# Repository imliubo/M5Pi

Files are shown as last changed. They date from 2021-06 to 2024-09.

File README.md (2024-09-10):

# M5Pi
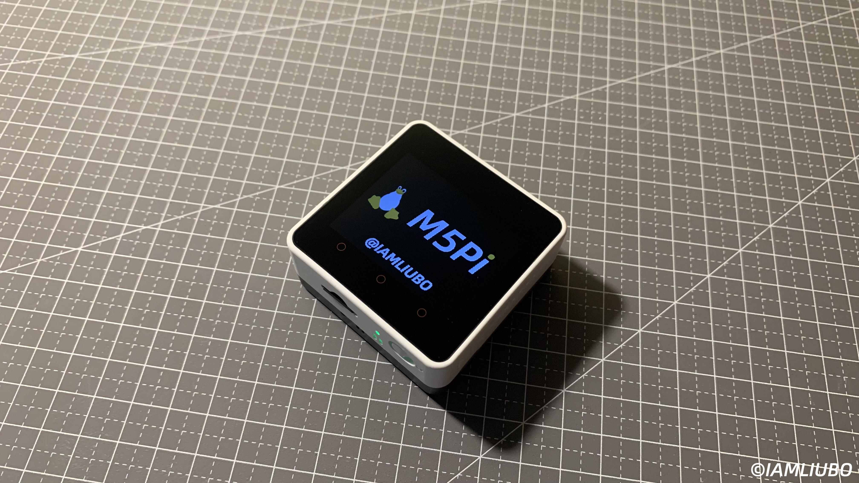
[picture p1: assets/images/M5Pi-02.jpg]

M5Pi is an open source Linux embedded development board, using Allwinner F1C200s CPU, and has a beautiful shell.

## Try to use a pre-compiled system image
```shell
wget https://github.com/imliubo/M5Pi/releases/download/v0.1-alpha/M5Pi-sysimage-sdcard-v0.1-alpha.tar.gz
tar -zxvf M5Pi-sysimage-sdcard-v0.1-alpha.tar.gz
dd if=sysimage-sdcard.img of=/dev/sdX  # Please make sure "X" is your TF card mount point.
```

## Try to compile your custom system image

### Install
```shell
sudo apt install wget unzip build-essential git bc swig libncurses-dev libpython3-dev libssl-dev
sudo apt install python3-distutils
```

### Build
```shell
git clone --recursive https://github.com/imliubo/M5Pi
cd M5Pi/buildroot-M5Pi
make IAMLIUBO_m5pi_defconfig  # Use the default config.
make -j ${YOUR_CPU_COUNT}
```

### Build with custom config
```shell
make menuconfig
make uboot-menuconfig
make linux-menuconfig
```

### Flash
```shell
dd if=buildroot-M5Pi/output/images/sysimage-sdcard.img of=/dev/sdX  # Please make sure "X" is your TF card mount point.
```

## License
1. Hardware: CC BY-NC-SA 4.0
2. buildroot-M5Pi: follow the upstream

## Links
[【自 制】这 可 能 是 最 精 致 的 Pi 了【Linux 小主机 | 开 源 | 硬 核】](https://www.bilibili.com/video/BV1RV411W7eH/)

[[开源项目-记录贴]扔掉你手中的开发板，跟我来自制基于F1C100s/F1C200s的M5Pi吧!](https://whycan.com/t_6402.html)

[How-to-make-a-M5Pi](./Tutorials/How-to-make-a-M5Pi.md)

## Thanks to the sponsor Seeed!
Seeed Fusion PCB Assembly Service offers one-stop prototyping for PCB manufacture, PCB assembly and as a result they produce superior quality PCBs and Fast Turnkey PCBA from 7 working days. When you prototype with Seeed Fusion, they can definitely provide Free DFA and Free functional tests for you! Check out their website to know more: https://www.seeedstudio.com/prototype-pcb-assembly.html

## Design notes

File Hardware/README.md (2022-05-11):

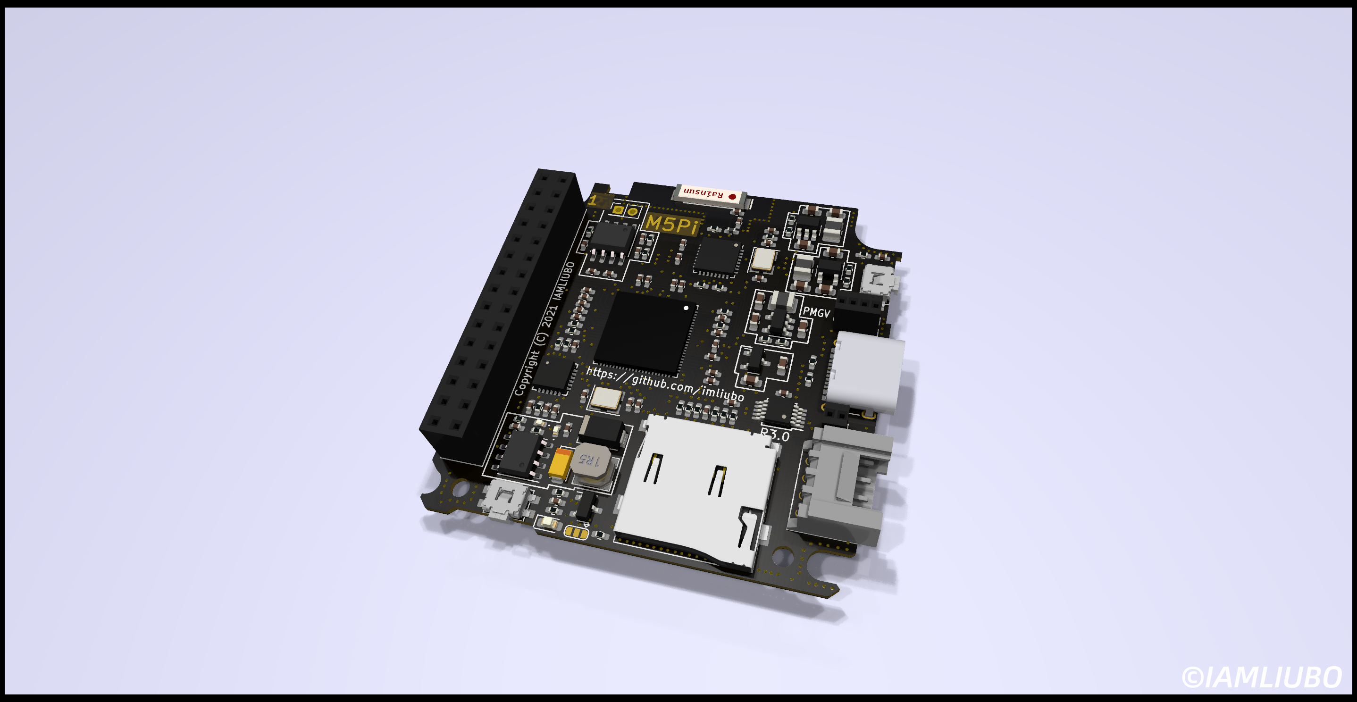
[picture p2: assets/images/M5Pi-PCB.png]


### CAUTION 

Please use the kicad-nightly version to open the projects.

etc. 
```bash
Version: 6.99.0-unknown-c34fb494b1~148~ubuntu20.04.1, release build
```

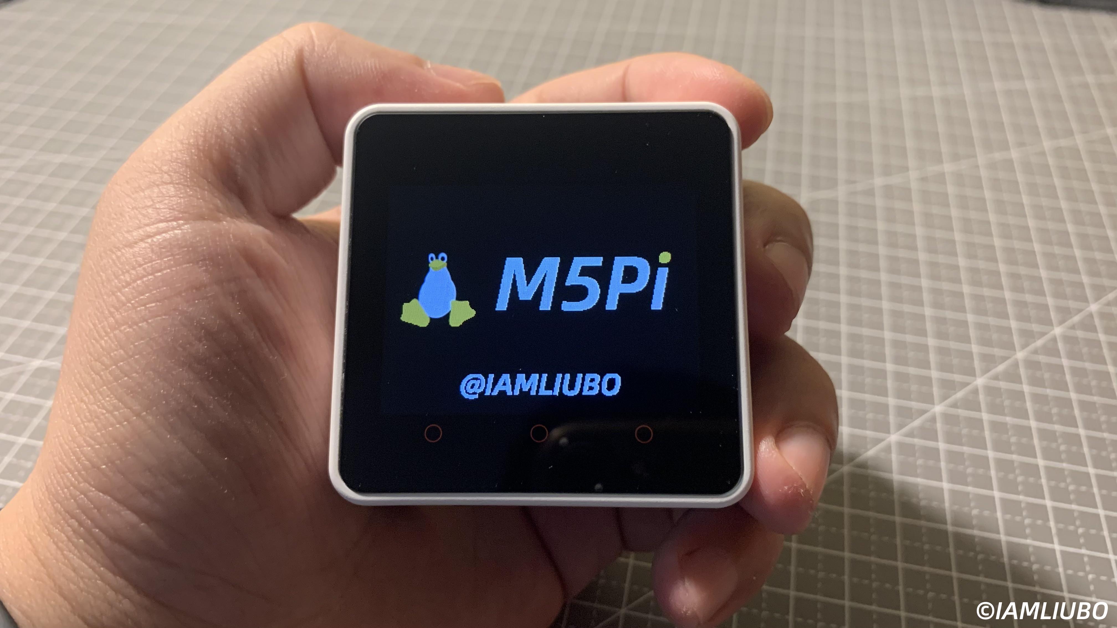
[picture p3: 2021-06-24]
assets/images/M5Pi-01.jpg

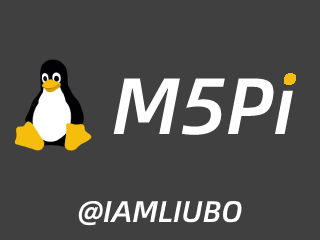
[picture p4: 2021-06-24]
assets/images/M5Pi.png

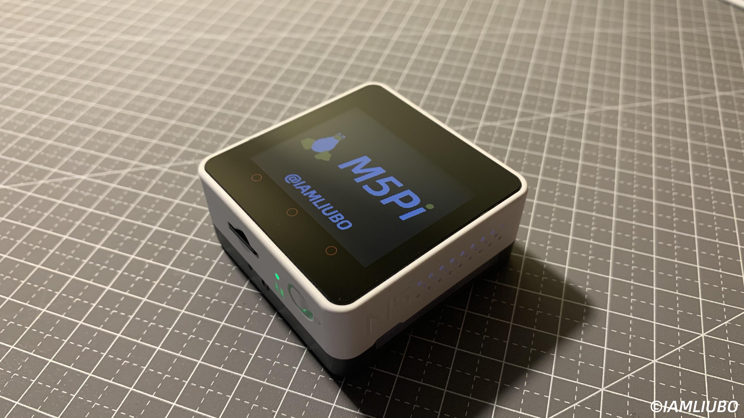
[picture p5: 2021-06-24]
assets/images/M5Pi-03.jpg

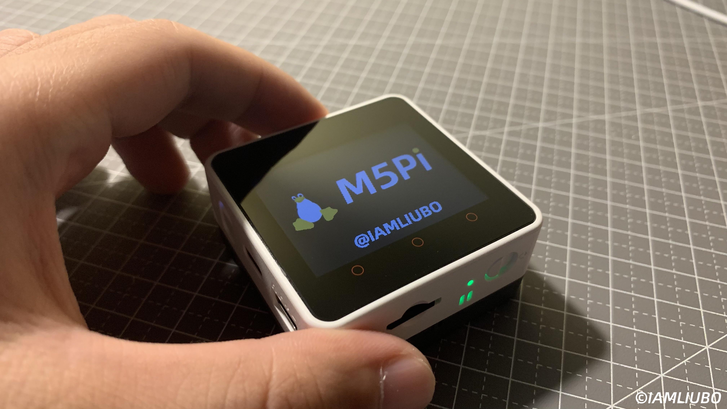
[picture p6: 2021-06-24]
assets/images/M5Pi-04.jpg

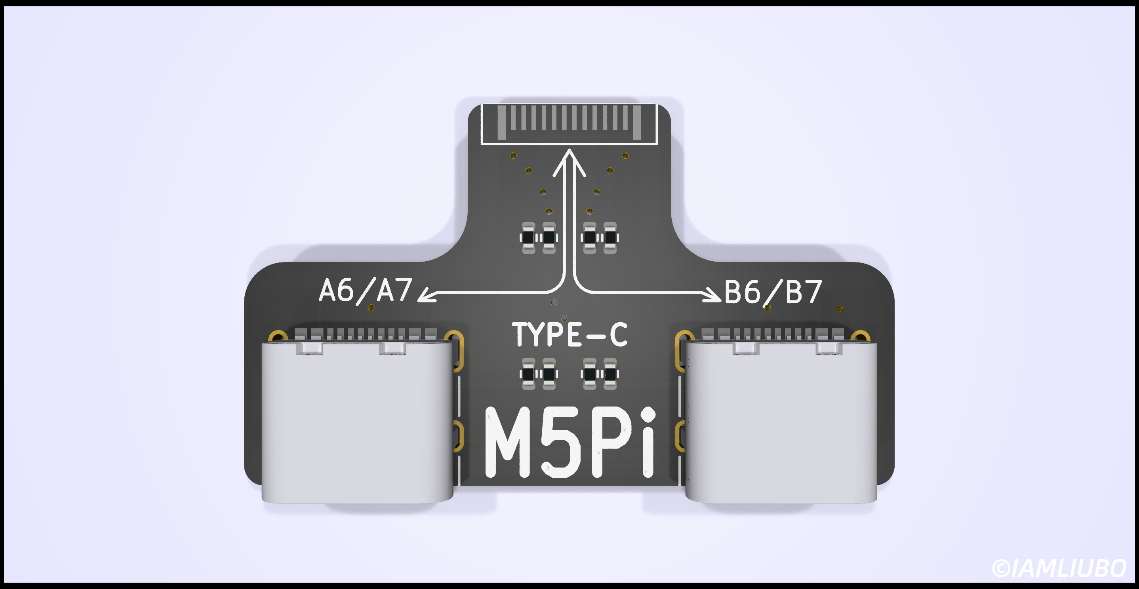
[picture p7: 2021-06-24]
assets/images/M5Pi-TYPE-C.png

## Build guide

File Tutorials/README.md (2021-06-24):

# Tutorials
The tutorial is not ready yet.

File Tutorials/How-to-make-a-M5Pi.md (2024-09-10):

# How to make a M5Pi :)

## 是什么

M5Pi是我最近自制并开源的嵌入式Linux开发板，基于全志科技的F1C200s芯片，板载MPU6050姿态传感器，拥有一个320x240分辨率，2寸大小的全贴合电容触摸显示屏，一个1W的小喇叭可以用来播放声音，Wi-Fi用的是ESP8089，最重要的是有一个精美的外壳，这也是为什么我称它为最精致的“Pi”的原因，项目完全开源，PCB使用的开源软件KiCAD绘制，部分3D模型使用的开源软件FreeCAD绘制，系统使用的比较流行的buildroot制作，还用LVGL写了个简单的Launcher(还没完全写完)。



## 为什么做

其实接触嵌入式Linux已经蛮久了，从最开始的树莓派，到后来NanoPi、香橙派、荔枝派等等，基本上也是都有玩过，还在B站录制过几集纯萌新入门视频，不过平常工作也不是主要做Linux相关的，所以理解的和讲的都很浅薄，真正让自己想要从零开始做一个属于自己的“Pi”，还是去年看到稚晖做的小电脑，当时觉得非常不错，自己也想去做一个，不过后面实际尝试了下，难度系数还是颇高的，所以当时用ESP32-S2做了个单片机版的小电视玩了玩，不过这个想法从未消失。


[](https://www.bilibili.com/video/BV19p4y1Q7yP)

## 做了哪些尝试

第二次想做，应该是在去年的十一月份左右，因为当时M5Core2玩了蛮久了，觉得这个尺寸，这个外壳，还有触摸的屏幕简直是太棒了，刚好我近水楼台先得月，手头也有外壳也有显示屏，所以当时又想去尝试一下，还特地选择了全志的H5，然后各种逛论坛，找资料，下载资料，真正开始要画PCB的时候，就觉得还是差点儿事了，因为H5没有内置DDR，我还想加一个eMMC，这部分属于高速PCB范畴了，挺难整的，只是简单打了一版布局的PCB，看了看主要元器件就放弃了，因为受制于外壳的尺寸，正面空间还是蛮小的，放背面我还不确定跟屏幕会不会有干涉，以及发热会不会影响屏幕等，就又咕掉了。

背面还有两颗DDR，还没layout就觉得难整了


不过也没有完全咕掉，我还是成功曲线救国，做了一版试了试，不过是用的友善之臂的NanoPi NEO Air核心板，然后画了个扩展版，成功试制了一版，虽然曲线救国，尺寸也不太合适等等众多小问题，但是效果还是非常棒的!跑的是Armbian，驱动屏幕的时候也是翻车了很久，怎么搞都没法点亮，最后发现问题是FPC座子虚焊了... 当时差点儿想拍死自己。



正面看还是蛮不错的，但是看看背面就有点惨不忍睹了...


## 怎么做的

用NanoPi搞完后，就懒惰了(其实是菜)，想用性能高点的CPU，PCB搞不定，PCB能搞定的，性能又不高，陷入了很长时间的CPU选型阶段，总体思想就是选内置DDR的，性能还要高点的，其实刚开始M5Pi没有准备用F1C200s，当时是看上了SSD202，因为刚好我司在做一个项目(Unit V2)，刚好也了解一点，但是这个片子的资料需要签NDA，那我后期开源肯定会受到影响，所以还不如选择一款大家用的多，虽然官方也没公开release过任何资料的片子，最后的焦点就放在了F1C和V3s上，虽然V3s性能要比F1C高，但是价格还是要贵一丢丢，而且第一次做，还是找个便宜点的吧，于是就这样定了下来，四月底就正式开始搞了，内置DDR的片子画起来，要简单很多，基本上只要电源没问题，晶振没问题，就可以正常跑起来了...(省略几千字，开发记录可以在坑网看到，链接在文章最后)




PCB第一版就可以正常运行，只不过触摸跟LED都画反了，别的没什么大碍，然后软件开发也就挺顺利的，因为aodzip大佬已经做了很多适配了，所以就简单改改设备树之类的，就平平无奇的运行起来了，不如上一次因为焊接问题，结果搞了好几天软件有意思(ahhhh)，有点凡尔赛了，其实从开始做，到正常运行还是花了蛮久的时间的，基本都是周末搞，PCB其实也打了好几版，主要是布局好，为了看结构需要打板测试。开发过程中最崩溃的莫过于焊接了，说多了都是泪，焊接太费事了...



## 收获了什么

M5Pi做了很久，做的还是非常开心的，这种感觉只有自己亲自去做，然后一点点调试，调试一个功能就行一个功能的感觉妙不可言~ 完整的做一个小项目还是比较爽的，建议大家也可以去尝试下，B站很多同学私信我是怎么学习，怎么开发的，我觉得还是多动手，多实践是最好的方法。M5Pi还没有完全开发完成，不过我已经开始着手准备下一个版本了！



## 大感谢

做M5Pi的过程中也收到了很多人的帮助，首先感谢哇酷网(原坑网)的各位坛友，然后是我的BOSS，哈哈，免费提供了我几套外壳(遗憾的是显示屏仓库缺货)，还有实验室可以让我在周末瞎搞，再然后是全志的Kirin，还送了我一个哪吒D1开发板，最后就是将各种问题记录并分享出来的网友们!

最后，项目是开源的，可以在我的Github仓库找到。

## 相关链接

1. https://github.com/imliubo/M5Pi
2. https://www.bilibili.com/video/BV1RV411W7eH
3. https://whycan.com/viewtopic.php?id=6402&action=onlyshowauthor

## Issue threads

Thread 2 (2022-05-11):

error when open kicad file in R4 folder

kawashimaken, 2022-05-11:
Thank you for sharing this great project!

An error occurred when opening the KiCad file in the R4 folder.
The KiCad file in R3 folder had no problem.
I am using KiCad 6.01 (6.05 shows the same error), should I switch to KiCad 5? or Do I have to use a specific version of KiCad?
Thank you!

imliubo, 2022-05-11:
Sorry,I must not have mentioned, I am using kicad-nightly, please try again with the kicad-nighly version.

kawashimaken, 2022-05-11:
Thank you!
I will try kicad-nighly next!

Closed 2022-05-17.

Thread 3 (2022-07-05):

kicad封装问题

apple596, 2022-07-05:
请问kicad的F1C200S的封装和原理图是在哪里找的，非常感谢。

imliubo, 2022-07-27:
好像是[这里](https://www.thirtythreeforty.net/)

Closed 2022-08-23.

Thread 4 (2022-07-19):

M5Pi-Launcher中的库缺少CMakeList.txt，编译失败

xxzling, 2022-07-19:
您好，M5Pi-Launcher中的库缺少CMakeList.txt，例如lv_fs_if、nes等，导致编译失败，手动添加内容为file(GLOB SOURCES *.c)后又不能生成*.a文件，请问有什么解决方法吗？

imliubo, 2022-08-23:
看一下 [M5Pi-Launcher](https://github.com/imliubo/M5Pi-Launcher/tree/870a251a8f5348b5696e45d8034bc286631881a7)中的 patch 文件夹和 顶层 CMakeList.tx

Closed 2022-10-10.

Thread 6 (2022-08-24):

power and buttons and network

sp00ck, 2022-08-24:
Is possible add knob/rotor for setup, change volume etc.
and outside (on edges) 2-3 buttons

I think the 18650 power will be great but not one but 2 independent. 2 different size (capacity) or old and new
charging separately and use separately. For example when device work i can get battery and put it to flashlight and device still work or... this same. When my computer have less power i can replace one cell from my mp3 player.

I hate sd card, why not using normal usb host A ? normal flash disk for system. cheap and usefull.
And please add irda (infrared)

for increase working time meybe put phisical switch for every system, turn off screen, sound, irda, meybe decrease speed of memory or cpu.

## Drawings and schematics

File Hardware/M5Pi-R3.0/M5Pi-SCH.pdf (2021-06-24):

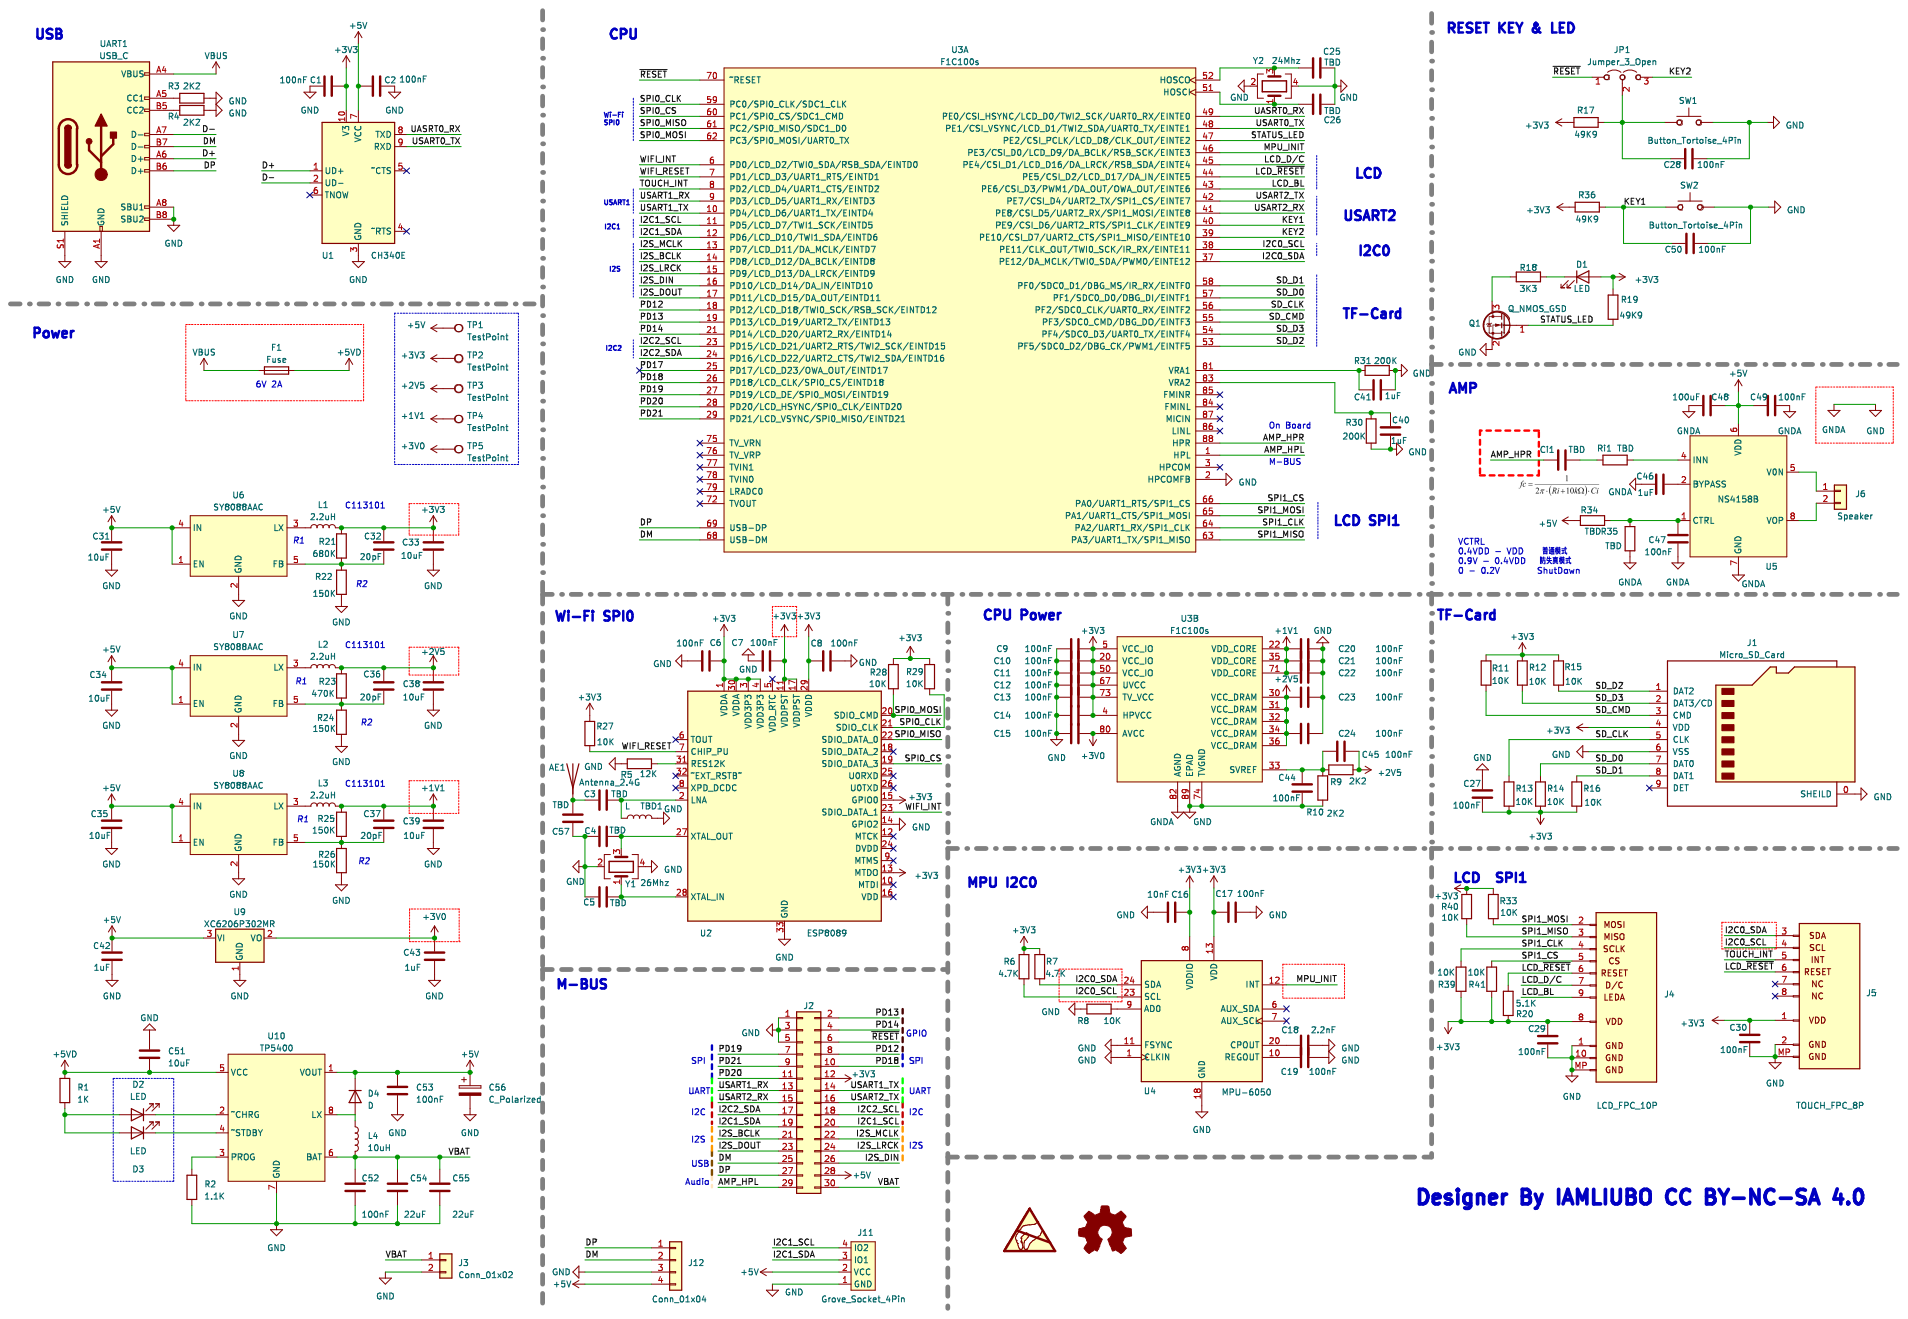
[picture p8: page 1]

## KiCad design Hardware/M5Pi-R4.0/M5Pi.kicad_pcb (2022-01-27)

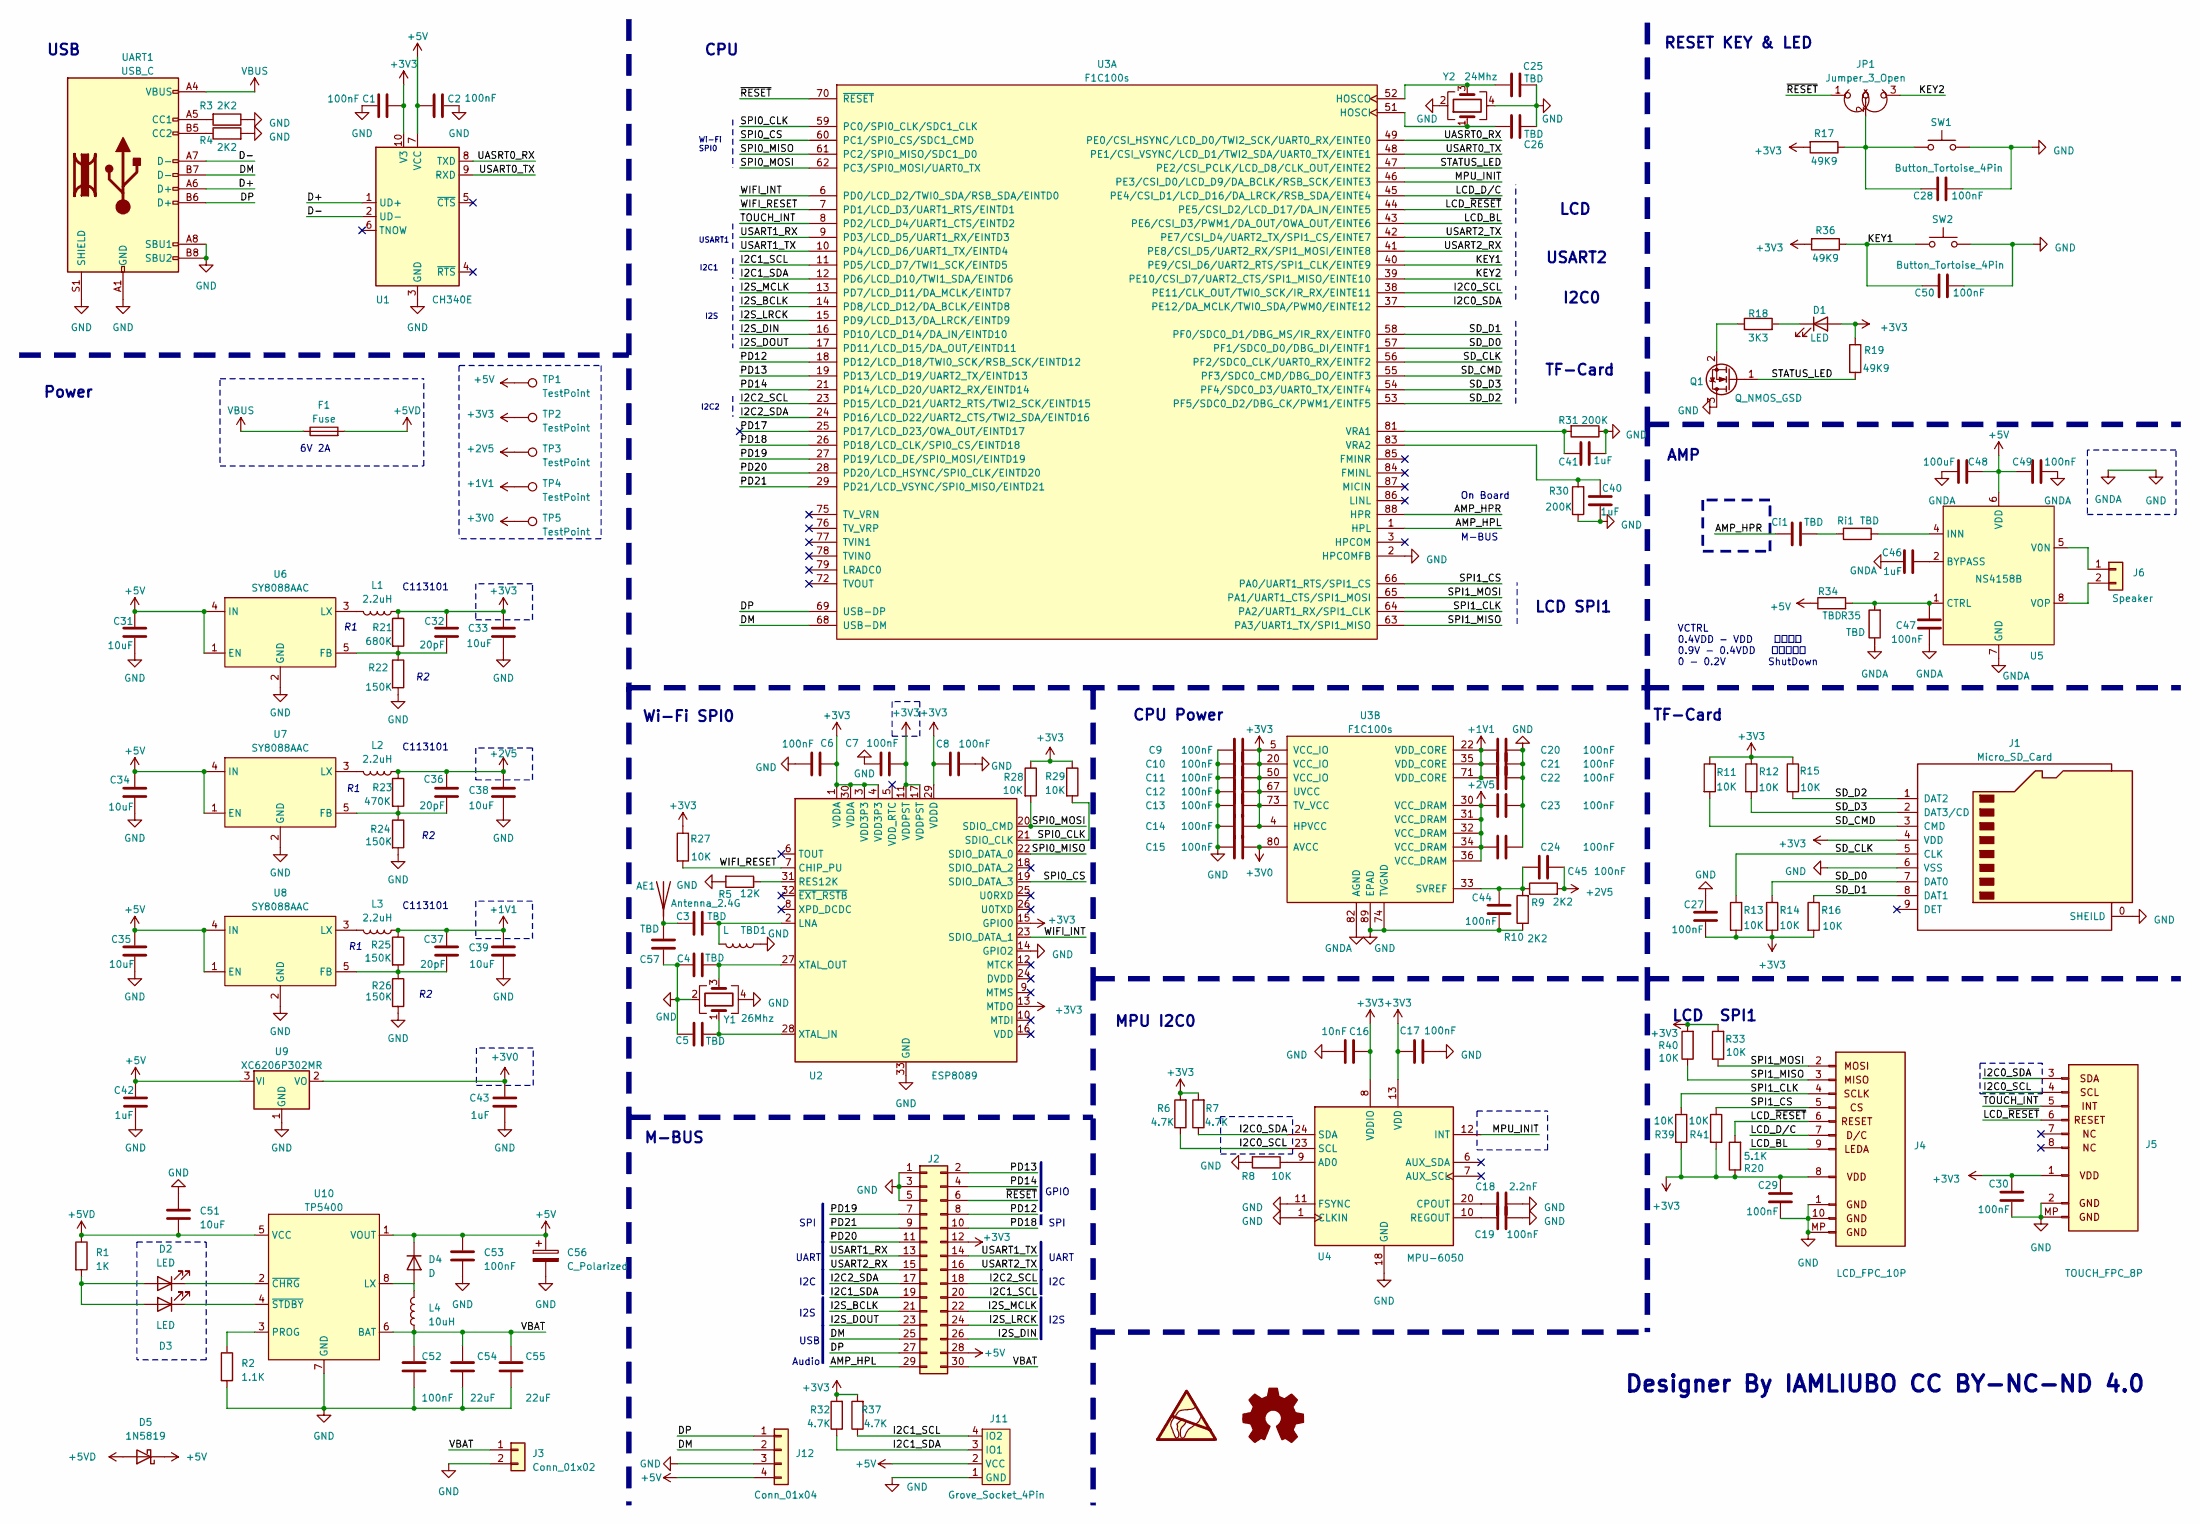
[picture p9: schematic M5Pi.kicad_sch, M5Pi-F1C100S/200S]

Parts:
AE1: Antenna_2.4G; ANT-2.4GHZ-9.5X2.0MM
C1, C2, C6, C7, C8, C9, C10, C11, C12, C13, C14, C15, C17, C19, C20, C21, C22, C23, C24, C27, C28, C29, C30, C44, C45, C47, C49, C50, C52, C53: 100nF; C_0402_1005Metric_Pad0.74x0.62mm_HandSolder
C3, C4, C5, C25, C26, C57: TBD; C_0402_1005Metric_Pad0.74x0.62mm_HandSolder
C16: 10nF; C_0402_1005Metric_Pad0.74x0.62mm_HandSolder
C18: 2.2nF; C_0402_1005Metric_Pad0.74x0.62mm_HandSolder
C31, C33, C34, C35, C38, C39: 10uF; C_0603_1608Metric
C32, C36, C37: 20pF; C_0603_1608Metric
C40, C41, C46: 1uF; C_0402_1005Metric_Pad0.74x0.62mm_HandSolder
C42, C43: 1uF; C_0603_1608Metric
C48: 100uF; C_0402_1005Metric_Pad0.74x0.62mm_HandSolder
C51: 10uF; C_0402_1005Metric_Pad0.74x0.62mm_HandSolder
C54, C55: 22uF; C_0402_1005Metric_Pad0.74x0.62mm_HandSolder
C56: C_Polarized; CP_EIA-3216-10_Kemet-I
Ci1: TBD; C_0402_1005Metric_Pad0.74x0.62mm_HandSolder
D1: LED; LED_0603_1608Metric_Pad1.05x0.95mm_HandSolder
D2, D3: LED; LED_0402_1005Metric
D4: D; D-SMA(DO-214AC)
D5: 1N5819; D_SOD-123
F1: Fuse; Fuse_1206_3216Metric
J1: Micro_SD_Card; MicroSD_Socket_push
J2: Conn_02x15_Odd_Even; PinHeader_2x15_P2.54mm_Vertical
J3: Conn_01x02; PinSocket_1x02_P1.27mm_Vertical
J4: LCD_FPC_10P; TE_1-1734839-0_1x10-1MP_P0.5mm_Horizontal
J5: TOUCH_FPC_8P; TE_0-1734839-8_1x08-1MP_P0.5mm_Horizontal
J6: Speaker; PinHeader_2x01_P2.00mm_Vertical
J11: Grove_Socket_4Pin; Grove_Socket_4Pin_2mm
J12: Conn_01x04; PinSocket_1x04_P1.27mm_Vertical
JP1: Jumper_3_Open; SolderJumper-3_P1.3mm_Open_RoundedPad1.0x1.5mm
L1, L2, L3: 2.2uH; L_1008_2520Metric
L4: 10uH; L_Sunlord_SWPA4030S_4x4x3mm
Q1: Q_NMOS_GSD; SOT-23
R1: 1K; R_0402_1005Metric
R2: 1.1K; R_0402_1005Metric
R3, R4, R9, R10: 2K2; R_0402_1005Metric_Pad0.72x0.64mm_HandSolder
R5: 12K; R_0402_1005Metric_Pad0.72x0.64mm_HandSolder
R6, R7, R32, R37: 4.7K; R_0402_1005Metric_Pad0.72x0.64mm_HandSolder
R8, R11, R12, R13, R14, R15, R16, R27, R28, R29, R33, R39, R40, R41: 10K; R_0402_1005Metric_Pad0.72x0.64mm_HandSolder
R17, R19, R36: 49K9; R_0402_1005Metric_Pad0.72x0.64mm_HandSolder
R18: 3K3; R_0402_1005Metric_Pad0.72x0.64mm_HandSolder
R20: 5.1K; R_0402_1005Metric_Pad0.72x0.64mm_HandSolder
R21: 680K; R_0402_1005Metric
R22, R24, R25, R26: 150K; R_0402_1005Metric
R23: 470K; R_0402_1005Metric
R30, R31: 200K; R_0402_1005Metric_Pad0.72x0.64mm_HandSolder
R34, R35: TBD; R_0402_1005Metric_Pad0.72x0.64mm_HandSolder
Ri1: TBD; R_0402_1005Metric_Pad0.72x0.64mm_HandSolder
SW1, SW2: Button_Tortoise_4Pin; Button_4Pin_Tortoise
TBD1: L; L_0402_1005Metric_Pad0.77x0.64mm_HandSolder
TP1, TP2, TP3, TP4, TP5: TestPoint
U1: CH340E; MSOP-10_3x3mm_P0.5mm
U2: ESP8089; QFN-32-1EP_5x5mm_P0.5mm_EP3.45x3.45mm
U3: F1C100s; QFN-88_EP_10x10_Pitch0.4mm
U4: MPU-6050; InvenSense_QFN-24_4x4mm_P0.5mm
U5: NS4158B; SOP-8_3.9x4.9mm_P1.27mm
U6, U7, U8: SY8088AAC; SOT-23-5
U9: XC6206P302MR; SOT-23
U10: TP5400; SOP-8_4.8x6.0mm_P1.27mm_EP2.3x3.2mm
UART1: USB_C; USB_C_C393939
Y1: 26Mhz; Crystal_SMD_3225-4Pin_3.2x2.5mm
Y2: 24Mhz; Crystal_SMD_3225-4Pin_3.2x2.5mm

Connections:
+1V1: C20.1, C21.1, C22.1, C37.1, C39.1, L3.2, R25.1, TP4.1, U3.22 (VDD_CORE), U3.35 (VDD_CORE), U3.71 (VDD_CORE)
+2V5: C23.1, C24.1, C36.1, C38.1, C45.1, L2.2, R9.2, R23.1, TP3.1, U3.30 (VCC_DRAM), U3.31 (VCC_DRAM), U3.32 (VCC_DRAM), U3.34 (VCC_DRAM), U3.36 (VCC_DRAM)
+3V0: C15.2, C43.1, TP5.1, U3.80 (AVCC), U9.2 (VO)
+3V3: C1.1, C6.1, C7.2, C8.1, C9.2, C10.2, C11.2, C12.2, C13.2, C14.2, C16.1, C17.1, C27.1, C29.2, C30.2, C32.1, C33.1, D1.2 (A), J1.4 (VDD), J2.12, J4.8, J5.1, L1.2, R6.2, R7.2, R11.1, R12.1, R13.2, R14.2, R15.1, R16.2, R17.2, R19.1, R20.1, R21.1, R27.1, R28.1, R29.1, R32.2, R33.2, R36.2, R37.2, R39.2, R40.2, R41.2, TP2.1, U1.10 (V3), U2.1 (VDDA), U2.3 (VDD3P3), U2.4 (VDD3P3), U2.11 (VDDPST), U2.13 (MTDO), U2.15 (GPIO0), U2.17 (VDDPST), U2.29 (VDDD), U2.30 (VDDA), U3.4 (HPVCC), U3.5 (VCC_IO), U3.20 (VCC_IO), U3.50 (VCC_IO), U3.67 (UVCC), U3.73 (TV_VCC), U4.8 (VDDIO), U4.13 (VDD)
+5V: C2.1, C31.1, C34.1, C35.1, C42.1, C48.1, C49.2, C53.1, C56.1, D4.1 (K), D5.1 (K), J2.28, J11.2 (VCC), J12.4, R34.1, TP1.1, U1.7 (VCC), U5.6 (VDD), U6.1 (EN), U6.4 (IN), U7.1 (EN), U7.4 (IN), U8.1 (EN), U8.4 (IN), U9.3 (VI), U10.1 (VOUT)
+5VD: C51.2, D5.2 (A), F1.2, R1.1, U10.5 (VCC)
/AMP_HPL: J2.29, U3.1 (HPL)
/AMP_HPR: Ci1.1, U3.88 (HPR)
/D+: U1.1 (UD+), UART1.A6 (D+)
/D-: U1.2 (UD-), UART1.A7 (D-)
/DM: J2.25, J12.2, U3.68 (USB-DM), UART1.B7 (D-)
/DP: J2.27, J12.1, U3.69 (USB-DP), UART1.B6 (D+)
/I2C0_SCL: J5.4, R6.1, U3.38 (PE11/CLK_OUT/TWI0_SCK/IR_RX/EINTE11), U4.23 (SCL)
/I2C0_SDA: J5.3, R7.1, U3.37 (PE12/DA_MCLK/TWI0_SDA/PWM0/EINTE12), U4.24 (SDA)
/I2C1_SCL: J2.20, J11.4 (IO2), R37.1, U3.11 (PD5/LCD_D7/TWI1_SCK/EINTD5)
/I2C1_SDA: J2.19, J11.3 (IO1), R32.1, U3.12 (PD6/LCD_D10/TWI1_SDA/EINTD6)
/I2C2_SCL: J2.18, U3.23 (PD15/LCD_D21/UART2_RTS/TWI2_SCK/EINTD15)
/I2C2_SDA: J2.17, U3.24 (PD16/LCD_D22/UART2_CTS/TWI2_SDA/EINTD16)
/I2S_BCLK: J2.21, U3.14 (PD8/LCD_D12/DA_BCLK/EINTD8)
/I2S_DIN: J2.26, U3.16 (PD10/LCD_D14/DA_IN/EINTD10)
/I2S_DOUT: J2.23, U3.17 (PD11/LCD_D15/DA_OUT/EINTD11)
/I2S_LRCK: J2.24, U3.15 (PD9/LCD_D13/DA_LRCK/EINTD9)
/I2S_MCLK: J2.22, U3.13 (PD7/LCD_D11/DA_MCLK/EINTD7)
/KEY1: C50.1, R36.1, SW2.1, U3.40 (PE9/CSI_D6/UART2_RTS/SPI1_CLK/EINTE9)
/KEY2: JP1.3 (B), U3.39 (PE10/CSI_D7/UART2_CTS/SPI1_MISO/EINTE10)
/LCD_BL: J4.9, U3.43 (PE6/CSI_D3/PWM1/DA_OUT/OWA_OUT/EINTE6)
/LCD_D/C: J4.7, U3.45 (PE4/CSI_D1/LCD_D16/DA_LRCK/RSB_SDA/EINT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)
/LCD_~RESET: J4.6, J5.6, R20.2, U3.44 (PE5/CSI_D2/LCD_D17/DA_IN/EINTE5)
/MPU_INIT: U3.46 (PE3/CSI_D0/LCD_D9/DA_BCLK/RSB_SCK/EINTE3), U4.12 (INT)
/PD12: J2.8, U3.18 (PD12/LCD_D18/TWI0_SCK/RSB_SCK/EINTD12)
/PD13: J2.2, U3.19 (PD13/LCD_D19/UART2_TX/EINTD13)
/PD14: J2.4, U3.21 (PD14/LCD_D20/UART2_RX/EINTD14)
/PD17: U3.25 (PD17/LCD_D23/OWA_OUT/EINTD17)
/PD18: J2.10, U3.26 (PD18/LCD_CLK/SPI0_CS/EINTD18)
/PD19: J2.7, U3.27 (PD19/LCD_DE/SPI0_MOSI/EINTD19)
/PD20: J2.11, U3.28 (PD20/LCD_HSYNC/SPI0_CLK/EINTD20)
/PD21: J2.9, U3.29 (PD21/LCD_VSYNC/SPI0_MISO/EINTD21)
/SD_CLK: J1.5 (CLK), R13.1, U3.56 (PF2/SDC0_CLK/UART0_RX/EINTF2)
/SD_CMD: J1.3 (CMD), R11.2, U3.55 (PF3/SDC0_CMD/DBG_DO/EINTF3)
/SD_D0: J1.7 (DAT0), R14.1, U3.57 (PF1/SDC0_D0/DBG_DI/EINTF1)
/SD_D1: J1.8 (DAT1), R16.1, U3.58 (PF0/SDC0_D1/DBG_MS/IR_RX/EINTF0)
/SD_D2: J1.1 (DAT2), R15.2, U3.53 (PF5/SDC0_D2/DBG_CK/PWM1/EINTF5)
/SD_D3: J1.2 (DAT3/CD), R12.2, U3.54 (PF4/SDC0_D3/UART0_TX/EINTF4)
/SPI0_CLK: R29.2, U2.21 (SDIO_CLK), U3.59 (PC0/SPI0_CLK/SDC1_CLK)
/SPI0_CS: U2.19 (SDIO_DATA_3), U3.60 (PC1/SPI0_CS/SDC1_CMD)
/SPI0_MISO: U2.22 (SDIO_DATA_0), U3.61 (PC2/SPI0_MISO/SDC1_D0)
/SPI0_MOSI: R28.2, U2.20 (SDIO_CMD), U3.62 (PC3/SPI0_MOSI/UART0_TX)
/SPI1_CLK: J4.4, R39.1, U3.64 (PA2/UART1_RX/SPI1_CLK)
/SPI1_CS: J4.5, R41.1, U3.66 (PA0/UART1_RTS/SPI1_CS)
/SPI1_MISO: J4.3, R40.1, U3.63 (PA3/UART1_TX/SPI1_MISO)
/SPI1_MOSI: J4.2, R33.1, U3.65 (PA1/UART1_CTS/SPI1_MOSI)
/STATUS_LED: Q1.1 (G), R19.2, U3.47 (PE2/CSI_PCLK/LCD_D8/CLK_OUT/EINTE2)
/TOUCH_INT: J5.5, U3.8 (PD2/LCD_D4/UART1_CTS/EINTD2)
/UASRT0_RX: U1.8 (TXD), U3.49 (PE0/CSI_HSYNC/LCD_D0/TWI2_SCK/UART0_RX/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)
/USART0_TX: U1.9 (RXD), U3.48 (PE1/CSI_VSYNC/LCD_D1/TWI2_SDA/UART0_TX/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)
/USART1_RX: J2.13, U3.9 (PD3/LCD_D5/UART1_RX/EINTD3)
/USART1_TX: J2.14, U3.10 (PD4/LCD_D6/UART1_TX/EINTD4)
/USART2_RX: J2.15, U3.41 (PE8/CSI_D5/UART2_RX/SPI1_MOSI/EINTE8)
/USART2_TX: J2.16, U3.42 (PE7/CSI_D4/UART2_TX/SPI1_CS/EINTE7)
/VBAT: C52.1, C54.1, C55.1, J2.30, J3.1, L4.2, U10.6 (BAT)
/WIFI_INT: U2.23 (SDIO_DATA_1), U3.6 (PD0/LCD_D2/TWI0_SDA/RSB_SDA/EINTD0)
/WIFI_RESET: R27.2, U2.7 (CHIP_PU), U3.7 (PD1/LCD_D3/UART1_RTS/EINTD1)
/~RESET: J2.6, JP1.1 (A), U3.70 (~RESET)
GND: C1.2, C2.2, C4.1, C5.1, C6.2, C7.1, C8.2, C9.1, C10.1, C11.1, C12.1, C13.1, C14.1, C15.1, C16.2, C17.2, C18.2, C19.2, C20.2, C21.2, C22.2, C23.2, C24.2, C25.1, C26.1, C27.2, C28.2, C29.1, C30.1, C31.2, C33.2, C34.2, C35.2, C38.2, C39.2, C40.1, C41.1, C42.2, C43.2, C44.1, C46.1, C47.1, C48.2, C49.1, C50.2, C51.1, C52.2, C53.2, C54.2, C55.2, C56.2, C57.1, J1.0 (SHEILD), J1.6 (VSS), J2.1, J2.3, J2.5, J3.2, J4.1, J4.10, J4.MP (Pin_10), J5.2, J5.MP (Pin_2), J11.1 (GND), J12.3, Q1.3 (D), R2.2, R3.1, R4.2, R5.2, R8.2, R10.1, R22.2, R24.2, R26.2, R30.1, R31.1, R35.1, SW1.2, SW2.2, TBD1.2, U1.3 (GND), U2.14 (GPIO2), U2.33 (GND), U3.2 (HPCOMFB), U3.74 (TVGND), U3.82 (AGND), U3.89 (EPAD), U4.1 (CLKIN), U4.11 (FSYNC), U4.18 (GND), U5.7 (GND), U6.2 (GND), U7.2 (GND), U8.2 (GND), U9.1 (GND), U10.7 (GND), UART1.A1 (GND), UART1.A8 (SBU1), UART1.A12 (GND), UART1.B1 (GND), UART1.B8 (SBU2), UART1.B12 (GND), UART1.S1 (SHIELD), Y1.2, Y1.4, Y2.2, Y2.4
unnamed: AE1.FEED, C3.1, C57.2
unnamed: Ci1.2, Ri1.2
unnamed: D1.1 (K), R18.2
unnamed: D2.2 (A), D3.2 (A), R1.2
unnamed: D2.1 (K), U10.2 (~CHRG)
unnamed: D3.1 (K), U10.4 (~STDBY)
unnamed: D4.2 (A), L4.1, U10.8 (LX)
unnamed: J6.1, U5.5 (V0N)
unnamed: J6.2, U5.8 (VOP)
unnamed: C28.1, JP1.2 (C), R17.1, SW1.1
unnamed: Q1.2 (S), R18.1
unnamed: C3.2, TBD1.1, U2.2 (LNA)
unnamed: R5.1, U2.31 (RES12K)
unnamed: C5.2, U2.28 (XTAL_IN), Y1.1
unnamed: C4.2, U2.27 (XTAL_OUT), Y1.3
unnamed: C26.2, U3.51 (HOSCI), Y2.1
unnamed: C25.2, U3.52 (HOSCO), Y2.3
unnamed: C41.2, R31.2, U3.81 (VRA1)
unnamed: C40.2, R30.2, U3.83 (VRA2)
unnamed: C44.2, C45.2, R9.1, R10.2, U3.33 (SVREF)
unnamed: R8.1, U4.9 (AD0)
unnamed: C18.1, U4.20 (CPOUT)
unnamed: C19.1, U4.10 (REGOUT)
unnamed: C46.2, U5.2 (BYPASS)
unnamed: C47.2, R34.2, R35.2, U5.1 (CTRL)
unnamed: Ri1.1, U5.4 (INN)
unnamed: C32.2, R21.2, R22.1, U6.5 (FB)
unnamed: L1.1, U6.3 (LX)
unnamed: C36.2, R23.2, R24.1, U7.5 (FB)
unnamed: L2.1, U7.3 (LX)
unnamed: C37.2, R25.2, R26.1, U8.5 (FB)
unnamed: L3.1, U8.3 (LX)
unnamed: R2.1, U10.3 (PROG)
unnamed: R3.2, UART1.A5 (CC1)
unnamed: R4.1, UART1.B5 (CC2)
VBUS: F1.1, UART1.A4 (VBUS), UART1.A9 (VBUS), UART1.B4 (VBUS), UART1.B9 (VBUS)

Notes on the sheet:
GPIO
I2S
Audio
I2C
UART
CPU Power
USART1
M-BUS
Designer By IAMLIUBO CC BY-NC-ND 4.0
Wi-Fi SPI0
AMP
C113101
RESET KEY & LED
USART2
On Board
USB
LCD SPI1
6V 2A
I2C2
Wi-Fi SPI0
LCD
TF-Card
MPU I2C0
LCD SPI1
Power
SPI
I2C1
CPU
I2C0
VCTRL 0.4VDD - VDD 普通模式 0.9V - 0.4VDD 防失真模式 0 - 0.2V ShutDown

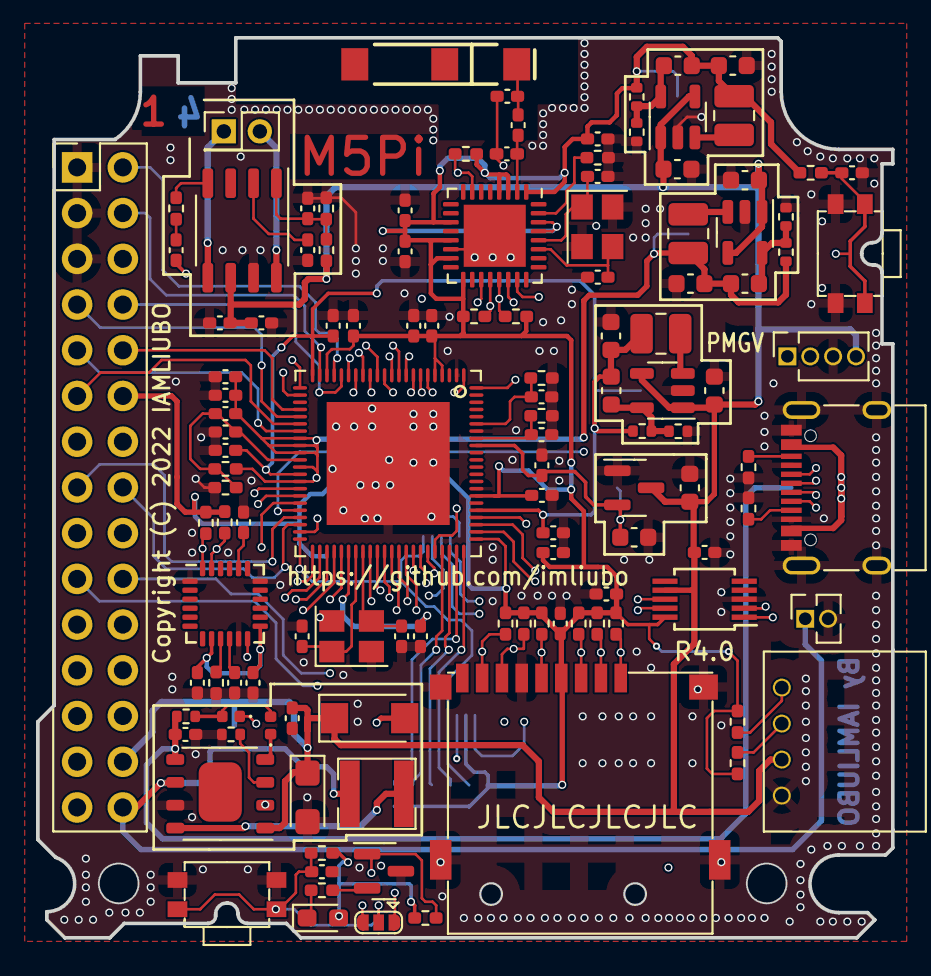
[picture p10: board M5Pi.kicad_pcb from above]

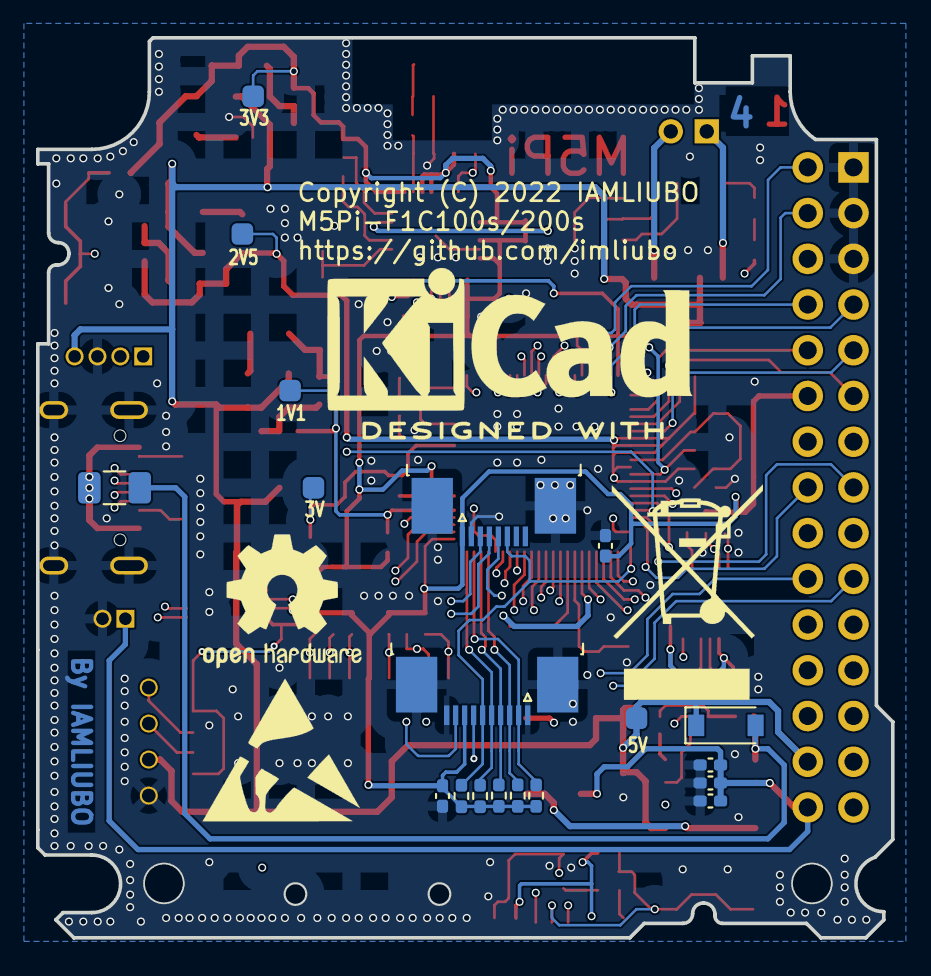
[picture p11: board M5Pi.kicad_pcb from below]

Board: 4 copper layers, 47.5 x 50.0 mm, 141 parts (19 on the bottom side), 99 nets.

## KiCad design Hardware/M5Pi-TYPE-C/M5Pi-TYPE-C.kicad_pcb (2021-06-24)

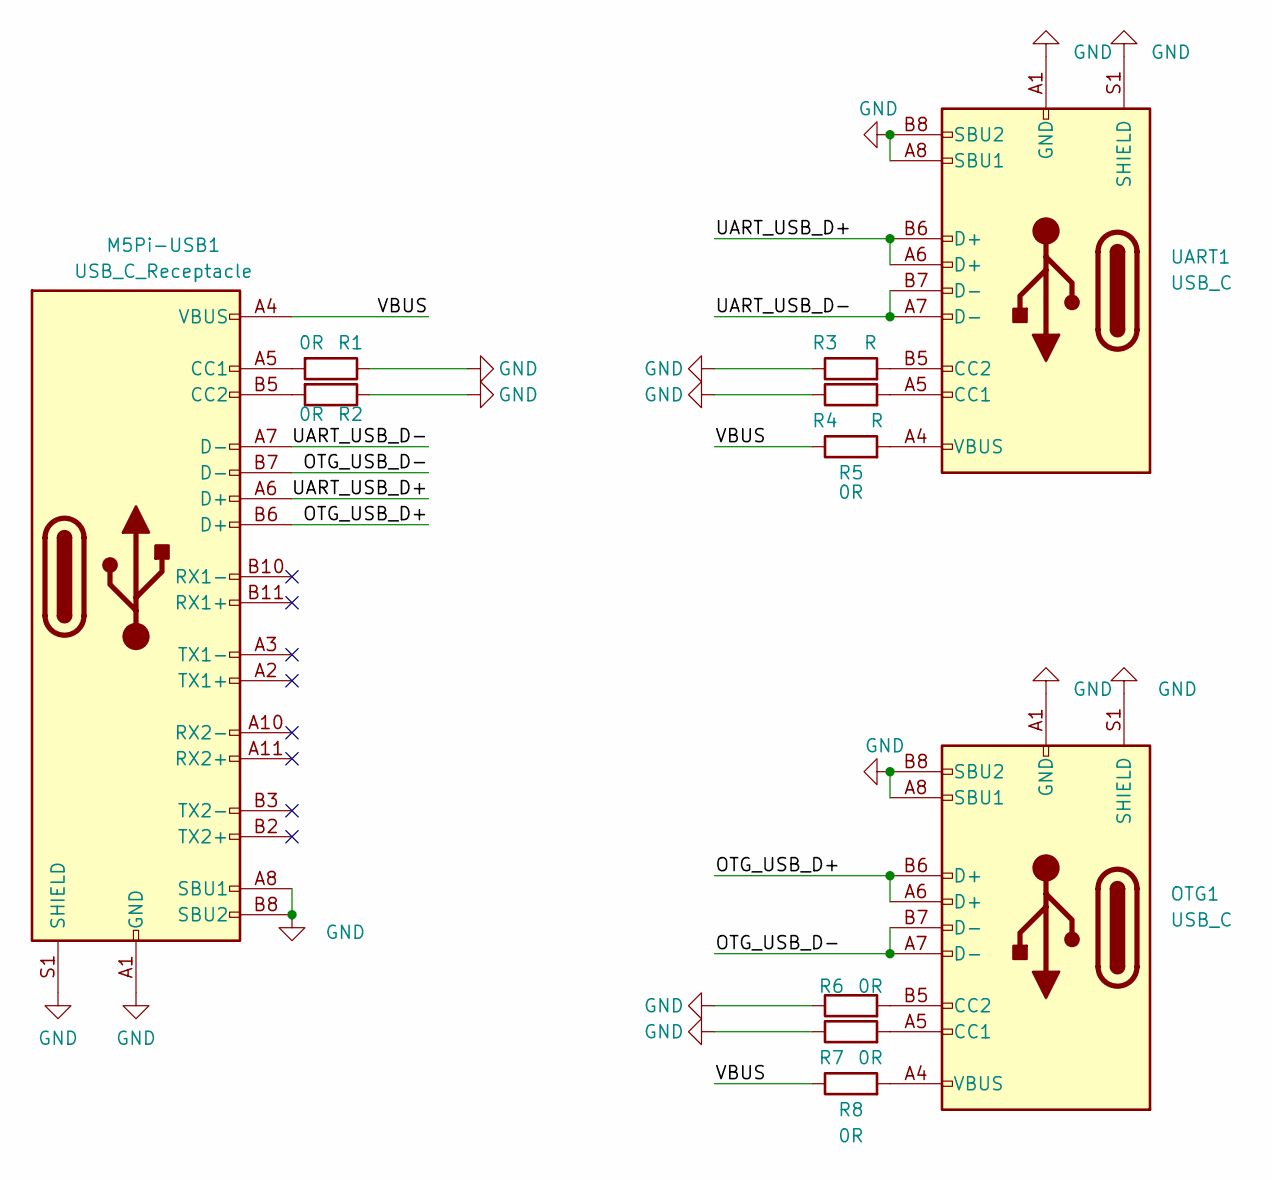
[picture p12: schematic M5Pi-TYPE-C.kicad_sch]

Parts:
M5Pi-USB1: USB_C_Receptacle; TYPE-C-31-G
OTG1: USB_C; USB_C_C393939
R1, R2, R5, R6, R7, R8: 0R; R_0402_1005Metric
R3, R4: R; R_0402_1005Metric
UART1: USB_C; USB_C_C393939

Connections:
/OTG_USB_D+: M5Pi-USB1.B6 (D+), OTG1.A6 (D+), OTG1.B6 (D+)
/OTG_USB_D-: M5Pi-USB1.B7 (D-), OTG1.A7 (D-), OTG1.B7 (D-)
/UART_USB_D+: M5Pi-USB1.A6 (D+), UART1.A6 (D+), UART1.B6 (D+)
/UART_USB_D-: M5Pi-USB1.A7 (D-), UART1.A7 (D-), UART1.B7 (D-)
/VBUS: M5Pi-USB1.A4 (VBUS), M5Pi-USB1.A9 (VBUS), M5Pi-USB1.B4 (VBUS), M5Pi-USB1.B9 (VBUS), R5.1, R8.1
GND: M5Pi-USB1.A1 (GND), M5Pi-USB1.A8 (SBU1), M5Pi-USB1.A12 (GND), M5Pi-USB1.B1 (GND), M5Pi-USB1.B8 (SBU2), M5Pi-USB1.B12 (GND), M5Pi-USB1.S1 (SHIELD), OTG1.A1 (GND), OTG1.A8 (SBU1), OTG1.A12 (GND), OTG1.B1 (GND), OTG1.B8 (SBU2), OTG1.B12 (GND), OTG1.S1 (SHIELD), R1.1, R2.1, R3.1, R4.1, R6.1, R7.1, UART1.A1 (GND), UART1.A8 (SBU1), UART1.A12 (GND), UART1.B1 (GND), UART1.B8 (SBU2), UART1.B12 (GND), UART1.S1 (SHIELD)
unnamed: M5Pi-USB1.A5 (CC1), R1.2
unnamed: M5Pi-USB1.B5 (CC2), R2.2
unnamed: OTG1.A4 (VBUS), OTG1.A9 (VBUS), OTG1.B4 (VBUS), OTG1.B9 (VBUS), R8.2
unnamed: OTG1.A5 (CC1), R7.2
unnamed: OTG1.B5 (CC2), R6.2
unnamed: R5.2, UART1.A4 (VBUS), UART1.A9 (VBUS), UART1.B4 (VBUS), UART1.B9 (VBUS)
unnamed: R4.2, UART1.A5 (CC1)
unnamed: R3.2, UART1.B5 (CC2)

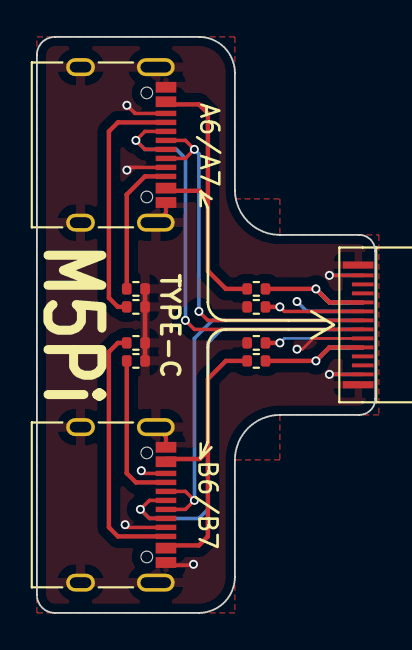
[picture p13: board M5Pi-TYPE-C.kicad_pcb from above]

Board: 2 copper layers, 18.8 x 32.0 mm, 11 parts (0 on the bottom side), 14 nets.

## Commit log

2022-01-27 PCB: upgrade version 4(NOT TEST)
    [M5Pi-B_Cu.gbr, M5Pi-B_Mask.gbr, M5Pi-B_Paste.gbr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]
2022-05-11 Add kicad notes

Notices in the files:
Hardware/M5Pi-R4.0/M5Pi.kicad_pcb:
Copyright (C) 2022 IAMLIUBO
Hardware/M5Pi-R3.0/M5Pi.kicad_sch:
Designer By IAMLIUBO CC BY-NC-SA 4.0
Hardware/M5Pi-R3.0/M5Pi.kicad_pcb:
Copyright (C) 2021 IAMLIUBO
